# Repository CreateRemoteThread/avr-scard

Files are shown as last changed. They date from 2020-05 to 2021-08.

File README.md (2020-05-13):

# avr-scard

this is an extremely minimal t0 iso7816 reader based off an atmega328p, communicating over serial at 9600 baud.

this implements a fixed wait after 5 bytes of APDU, but otherwise does not guarantee reponses for APDU's. the pyserial driver is currently a part of [sparkgap](https://github.com/createremotethread/sparkgap). The pin out is as follows:

- B4: Status LED
- B0: Target I/O
- B2: Target Reset
- B1: Target Clk
- C5: Trigger (after APDU Send)

this is based off https://www.makomk.com/2011/02/25/iso-7816-smartcard-interface-for-arduino/

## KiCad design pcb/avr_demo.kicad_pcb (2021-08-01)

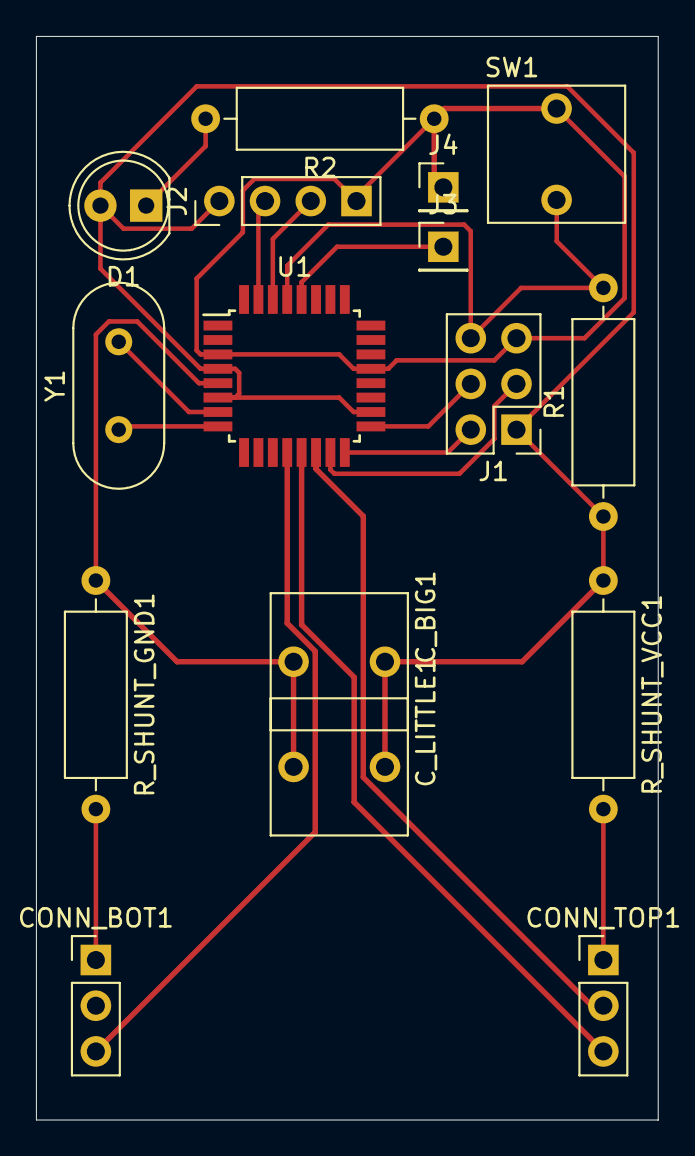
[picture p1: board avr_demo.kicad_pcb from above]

Board: 2 copper layers, 34.5 x 60.2 mm, 16 parts (0 on the bottom side), 17 nets.

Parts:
CONN_BOT1: Conn_01x03; PinHeader_1x03_P2.54mm_Vertical
CONN_TOP1: Conn_01x03; PinHeader_1x03_P2.54mm_Vertical
C_BIG1: C; SW_6x6
C_LITTLE1: C; SW_6x6
D1: LED; LED_D5.0mm
J1: AVR-ISP-6; AVRISP_2x3
J2: Conn_01x04; PinHeader_1x04_P2.54mm_Vertical
J3, J4: Conn_01x01_Male; PinHeader_1x01_P2.54mm_Vertical
R1, R2: R; R_Axial_DIN0309_L9.0mm_D3.2mm_P12.70mm_Horizontal
R_SHUNT_GND1: R; R_Axial_DIN0309_L9.0mm_D3.2mm_P12.70mm_Horizontal
R_SHUNT_VCC1: R; R_Axial_DIN0309_L9.0mm_D3.2mm_P12.70mm_Horizontal
SW1: SW_Push; SW_6x6
U1: ATmega328P-AU; TQFP-32_7x7mm_P0.8mm
Y1: Crystal; Crystal_HC49-4H_Vertical

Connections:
GND: C_BIG1.2, C_LITTLE1.2, J1.6, J2.4, J4.1, R2.1, R_SHUNT_GND1.1, SW1.1, U1.3, U1.5, U1.21
ISP_MISO: J1.1, U1.16
ISP_MOSI: J1.4, U1.15
ISP_RST: J1.5, R1.2, SW1.2, U1.29
ISP_SCK: J1.3, U1.17
unnamed: CONN_BOT1.1, R_SHUNT_GND1.2
unnamed: CONN_TOP1.1, R_SHUNT_VCC1.2
unnamed: D1.1, R2.2
unnamed: U1.7, Y1.2
unnamed: U1.8, Y1.1
SC_CLK: CONN_TOP1.3, U1.13
SC_DATA: CONN_BOT1.3, U1.12
SC_RST: CONN_TOP1.2, U1.14
SC_TRIG: J3.1, U1.28
USART_RX: J2.3, U1.30
USART_TX: J2.2, U1.31
VCC: C_BIG1.1, C_LITTLE1.1, D1.2, J1.2, J2.1, R1.1, R_SHUNT_VCC1.1, U1.4, U1.6, U1.18

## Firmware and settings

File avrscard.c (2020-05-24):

#define F_CPU 16000000L

#include <avr/io.h>
#include <avr/interrupt.h>
#include <stdlib.h>
#include <stdio.h>
#include <util/delay.h>
#include "pewpew.h"

#define BAUD 9600 // define baud
#define BAUDRATE ((F_CPU)/(BAUD*16UL)-1) // set baud rate value for UBRR

#define INPUT 0
#define OUTPUT 1

#define HIGH 1
#define LOW 0

#define bit(b) (1UL << (b))

#define LED PINB4
#define DATA PINB0
#define RESET PINB2
#define CLOCK PINB1
#define TRIGGER PINC5

//#define RAW_DUMP
//#define DOUBLE_RATE
//#define IN_WIRE_ORDER

#define SEND_BITCNT 11
uint8_t send_bits[SEND_BITCNT];
volatile uint8_t scnt, sending;

volatile uint8_t recv, rcnt;

char currentLed = 0;

void toggleLed()
{
	digitalWrite(LED,currentLed);
	currentLed = 1 - currentLed;
	return;
}

// TIMER2 comp A match - used to send bits on interface
ISR(TIMER2_COMPA_vect) {
	if (++scnt >= SEND_BITCNT) {
		TCCR2B = 0; // disable timer
		TIFR2 = _BV(OCF2A) | _BV(OCF2B); // clear interrupt flags
		digitalWrite(DATA, HIGH);
		pinMode(DATA, INPUT);
		PCIFR = _BV(PCIF0); // clear pin change flag
		PCICR = _BV(PCIE0); // re-enable pin change interrupt

		sending = 0;
		} else {
		digitalWrite(DATA, send_bits[scnt]);
	}
}

char digitalRead(char pinselect)
{
	char c = PINB;
	if((c & (1 << pinselect)) == 0)
	{
		return 0;
	}
	else
	{
		return 1;
	}
}

// TIMER2 comp B match - used to receive bits on interface.
// The reason we use different comparator registers when sending
// and receiving is becasuse we want to sample the bit in the
// middle of the bit period.

char rxBuf[256];
int rxLen = 0;

ISR(TIMER2_COMPB_vect) {
	unsigned char rbit = digitalRead(DATA);
	if (rcnt++ == 8) {
		// toggleLed();
		// FIXME - we should check parity here but don't!
		TCCR2B = 0; // disable timer
		//PCIFR = _BV(PCIF0); // clear pin change flag
		PCICR = _BV(PCIE0); // re-enable pin change interrupt
		// report the byte of data to the computer
		// putchar('.');
		// putchar(recv);
		rxBuf[rxLen++] = recv;
		} else {
		//if(rbit == 0) putchar('0');
		//if(rbit == 1)  putchar('1');
		recv |= (rbit << rcnt);
	}
}

// We use PCINT0 to detect the start of an incoming byte from
// the smart card and set up timer 2 to sample the incoming bits
ISR(PCINT0_vect) {
	// toggleLed();
	if (digitalRead(DATA) == 0) {
		TCNT2 = 0; //reset timer
		TCCR2B = 0 << CS22 | 1 << CS21 | 0 << CS20; // enable in divide-by-8 mode
		TIMSK2 = bit(OCIE2B); // turn on compare B interrupt.
		PCICR = 0; // disable pin change interrupt.
		#ifdef IN_WIRE_ORDER
		rcnt = 10;
		#else
		rcnt = 0xfe; recv = 0;
		#endif
		//putchar('S');
	}
}

void uart_init (void)
{
	UBRR0H = (BAUDRATE>>8); // shift the register right by 8 bits
	UBRR0L = BAUDRATE; // set baud rate
	UCSR0B|= (1<<TXEN0)|(1<<RXEN0); // enable receiver and transmitter
	UCSR0C = (3<<UCSZ00);
}

int uart_transmit(char data  )
{
	while (!( UCSR0A & (1<<UDRE0))); // wait while register is free
	UDR0 = data; // load data in the register
	return 0;
}

unsigned char uart_receive( void )
{
	while ( !(UCSR0A & (1<<RXC0)) );
	return UDR0;
}

unsigned int trigger_delay = 0;
unsigned int trigger_delay_ms = 0;

void sendAPDU(int length, char *buffer)
{
	int i = 0;
	if(length > 5)
	{
		for(i = 0;i < 5;i++)
		{
			sendISOChar(buffer[i]);
		}
		_delay_ms(100);
	}
	for(;i < length;i++)
	{
		sendISOChar(buffer[i]);
	}
	
	unsigned int delay_us_timer = 0;
	for(delay_us_timer = 0;delay_us_timer < trigger_delay;delay_us_timer++)
	{
		_delay_us(1);
	}
	for(delay_us_timer = 0;delay_us_timer < trigger_delay_ms;delay_us_timer++)
	{
		_delay_ms(1);
	}
	PORTC |= (1 << TRIGGER);
}

void main()
{
	uart_init();
	FILE mystdio = FDEV_SETUP_STREAM(uart_transmit, uart_receive, _FDEV_SETUP_RW);
	
	stdout = &mystdio;
	stdin = &mystdio;
	
	pinMode(LED, OUTPUT);
	_delay_ms(500);
	digitalWrite(LED, HIGH);
	_delay_ms(500);
	digitalWrite(LED, LOW);
	setup();
	
	int rxHead = 0;
	
	putchar('#');	
	putchar('\n');
	
	
	int idle = 0;
	while(1)
	{
		char ch = getchar();
		if (ch == 'R')
		{
			// pulse RESET signal LOW
			rxLen = 0;
			TCCR1B=0;
			TCCR1A=0;
			TCNT1=0;
			__asm__ __volatile__ ("nop");
			__asm__ __volatile__ ("nop");
			__asm__ __volatile__ ("nop");
			TCCR1A = 0x40;
			OCR1A = 1;
			TCCR1B = 0x09;
			__asm__ __volatile__ ("nop");
			__asm__ __volatile__ ("nop");
			__asm__ __volatile__ ("nop");
			digitalWrite(RESET, LOW);
			_delay_ms(50);
			digitalWrite(RESET, HIGH);
			putchar('A');
		} 
		else if (ch == 'r')
		{
			// pulse RESET signal HIGH
			rxLen = 0;
			TCCR1B=0;
			TCCR1A=0;
			TCNT1=0;
			__asm__ __volatile__ ("nop");
			__asm__ __volatile__ ("nop");
			__asm__ __volatile__ ("nop");
			TCCR1A = 0x40;
			OCR1A = 1;
			TCCR1B = 0x09;
			__asm__ __volatile__ ("nop");
			__asm__ __volatile__ ("nop");
			__asm__ __volatile__ ("nop");
			digitalWrite(RESET, HIGH);
			_delay_ms(50);
			digitalWrite(RESET, LOW);
			putchar('A');
		}
		else if(ch == 'a')
		{
			char txBuf[256];
			char txLen;
			int txHead = 0;
			txLen = getchar();
			for(txHead = 0;txHead < txLen;txHead++)
			{
				txBuf[txHead] = getchar();
			}
			sendAPDU(txLen,txBuf);
			
			PORTC &= ~(1 << TRIGGER);
		}
		else if(ch == 'd')
		{
			putchar('#');
			putchar(rxLen);
			rxHead = 0;
			int rxLenCache = rxLen;
			for(rxHead = 0;rxHead < rxLenCache;rxHead++)
			{
				putchar(rxBuf[rxHead]);
			}
			rxLen = 0;
		}
		else if(ch == 'w')
		{
			unsigned char b1 = getchar();
			unsigned char b2 = getchar();
			trigger_delay = (b1 * 0x100) + b2;
			putchar('!');
			putchar((trigger_delay >> 8 )& 0xFF);
			putchar(trigger_delay & 0xFF);
		}
		else if(ch == 'W')
		{
			unsigned char b1 = getchar();
			unsigned char b2 = getchar();
			trigger_delay_ms = (b1 * 0x100) + b2;
			putchar('!');
			putchar((trigger_delay_ms >> 8 )& 0xFF);
			putchar(trigger_delay_ms & 0xFF);
		}
	}
}

void setup() {
	sei();
	// TOP=OCR2A, disable
	TCCR2A = _BV(WGM21);
	TCCR2B = 0; // disable
	TIFR2 = _BV(OCF2A) | _BV(OCF2B); // clear interrupt flags

	#ifdef DOUBLE_RATE
	OCR2A = 93; // (372/2)/2
	OCR2B = 46; // OCR2A/2
	#else
	OCR2A = 186; // 372/2
	OCR2B = 93; // OCR2A/2
	#endif

	// TIMSK2 = _BIT(OCIE2A) for compare A interrupt, _BIT(OCIE2B) for compare B

	pinMode(DATA, INPUT);
	digitalWrite(DATA, HIGH); // enable internal pull-up.

	pinMode(RESET, OUTPUT);
	digitalWrite(RESET, LOW);
	_delay_ms(50);
	digitalWrite(RESET, HIGH); // FIXME

	// use timer 1 to generate a clock source
	pinMode(CLOCK, OUTPUT);
	TCCR1B = 0x00; // disable timer 1
	TCCR1A = 0x40; // normal mode, toggle OC1A on overflow
	// #ifdef DOUBLE_RATE
	// OCR1A = 0; // count to 0 for a clock of 16 MHz / (2*(0+1)) = 8Mhz
	// #else
	OCR1A = 1; // count to 1 for a clock of 16 MHz / (2*(1+1)) = 4Mhz
	// #endif
	TCCR1B = 0x09; // reset timer on OCR1 match, prescaler 1, enable.

	#ifdef RAW_DUMP
	PCICR = 0; // disable pin change interrupt.
	TCNT2 = 0; //reset timer
	TCCR2B = 0 << CS22 | 1 << CS21 | 0 << CS20; // enable in divide-by-8 mode
	TIMSK2 = _BV(OCIE2B); // turn on compare B interrupt.
	rcnt = 8;
	#else
	// Now enable pin change interrupt
	PCMSK0 = _BV(PCINT0);
	PCICR = _BV(PCIE0);
	#endif
	
	DDRC |= (1 << TRIGGER);
}

void sendISOChar(uint8_t c) {
	char parity = 0;
	cli();
	TCCR2B = 0; // disable timer
	TIFR2 = _BV(OCF2A) | _BV(OCF2B); // clear interrupt flags
	PCIFR = _BV(PCIF0); // clear pin change flag
	PCICR = 0; // disable pin change interrupt
	sei();

	for (char i = 0; i < 8; i++) {
		parity ^= (send_bits[i + 1] = (c >> i) & 1);
	}
	send_bits[9] = parity;
	for (char i = 10; i < SEND_BITCNT; i++) send_bits[i] = 1;

	sending = 1; scnt = 0;
	// DDRB |= (1 << PINB0);
	pinMode(DATA, OUTPUT);
	TCNT2 = 0; //reset timer
	TIMSK2 = bit(OCIE2A); // turn on compare A interrupt.
	TCCR2B = 0 << CS22 | 1 << CS21 | 0 << CS20; // enable in divide-by-8 mode
	digitalWrite(DATA, LOW);
	while (sending) /* wait */;

	#if 1
	PCMSK0 = _BV(PCINT0);
	PCICR = _BV(PCIE0);
	#endif
}

void digitalWrite(char pinselect, char direction)
{
	if(direction == HIGH)
	{
		PORTB |= (1 << pinselect);	
	}
	else
	{
		PORTB &= ~(1 << pinselect);	
	}
}

void pinMode(char pinselect,char direction)
{
	if(direction == INPUT)
	{
		DDRB &= ~(1 << pinselect);	
	}
	else
	{
		DDRB |= (1 << pinselect);
	}
}
